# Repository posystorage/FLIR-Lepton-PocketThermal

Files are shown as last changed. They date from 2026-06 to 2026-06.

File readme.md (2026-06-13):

# FLIR LWIR Firmware README

<p align="center">
  <a href="#中文">中文</a> · <a href="#english">English</a>
</p>

## 中文

> 中文为原文，英文为机器翻译，仅供海外读者快速了解。  
> 硬件开源说明见：[`hardware/hw.md`](hardware/hw.md)。相关硬件讨论也可参考https://oshwhub.com/posy/project_xbiozslm。
> 电路板文件以本仓库hw内的AD14工程为准。不要参考LCEDA!!!!!!画这个电路板的时候，LCEDA还相当不成熟呢。

### 项目简介

这是一个用于 FLIR Lepton 2.0 热成像摄像头模块的 MCU 固件项目，单片机基于 Nuvoton M484KIDIE，是一款 Cortex-M4F、192MHz 的主控。

目前功能包括：Lepton RAW14 热图采集、MCU 端图像增强（AGC、图像超分辨率）、LCD UI、HS USB 摄像头 + 读卡器、SD 卡拍照保存和电源管理。

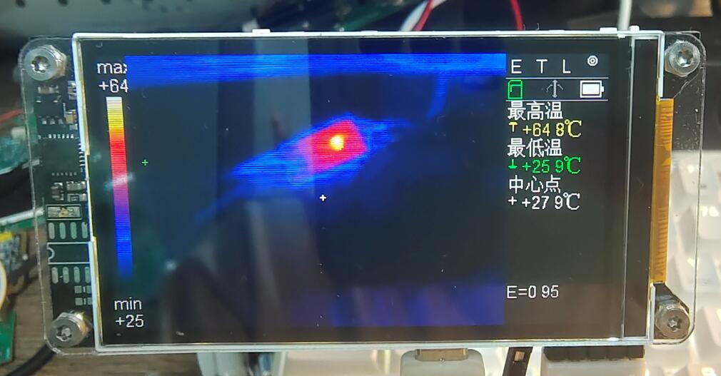
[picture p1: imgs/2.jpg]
热成像显示


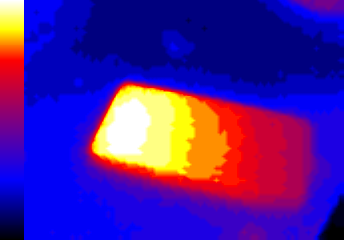
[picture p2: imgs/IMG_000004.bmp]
拍照保存 BMP 示例


Lepton 2.0 是一个 80x60 分辨率、不带测温功能的热成像摄像头模块，价格比较便宜。由于没有出厂校准的测温系数，本项目只能通过手算模型估算大致温度，可能需要二次校准才更接近真实值。建议把它作为相对温度变化的参考，而不是绝对测温仪器。

重要提醒：代码中有大量 vibe coding 内容，目前只测试了 happy path。虽然项目已经按现有文档和源码组织出完整框架，但使用、移植或复刻前必须仔细核对。

### 当前功能

- Lepton RAW14 采集，CCI 初始化和 VoSPI 帧读取。
- 512-bin Variant HEQ 风格 AGC。
- 80x60 到 320x240 的两级 2x 灰度超分。
- 支持多色卡 LUT，LCD 使用 RGB565 表，BMP 使用 RGB888 表，USB UVC 保留 YUV/灰度路径。
- RBFO 逆普朗克粗测温、发射率修正、中心/最高/最低/用户点测温。
- 432x240 手绘 UI：左侧 LUT、中间热图、右侧状态/菜单。
- MPU6050 姿态检测和 0/90/180/270 度 UI 适配。
- USB HS 复合设备：UVC 热成像摄像头 + MSC SD 读卡器。
- microSD + FatFS：保存 BMP/RAW/TXT。
- 电源管理：电池 ADC、充电状态、空闲/低电压关机、KEY1 长按关机。

### 软件架构

```text
USER/main.c
  -> SYS/       clock, tick, delay
  -> HARDWARE/  I2C, Lepton, LCD, SDH1, MPU6050, LP3921, key, UART
  -> APP/       image pipeline, UI, USB composite, UVC, storage, power manager
  -> thirdparty/fatfs/
```

主循环是裸机状态机调度，不使用 RTOS。对于一帧图像数据，当前约 8.5fps，图像处理流程约 75ms，LCD 显示约 15ms，还有约 30% 的处理器余量。HS UVC 上传仍然比较紧凑。

### 算法实现框架

图像处理分为显示链路和测温链路。AGC 只用于显示，不参与温度换算：

```text
Lepton RAW14[60][80]
  -> 显示链路: 512-bin AGC -> Gray8[60][80] -> 两级 2x 超分 -> Gray8[240][320]
  -> 测温链路: RBFO 逆普朗克 -> 发射率/校准 -> 测温点
```

超分算法位于 `firmware/APP/image_upscale.c`。它先在 80x60 灰度图上做方向感知 2x，得到 160x120；再用轻量 2x 得到 320x240；最后使用受限轻锐化。这样可以避免在伪彩色 RGB 空间插值产生色边，也能减轻普通最近邻 4x 的明显块状感。

图像流水线位于 `firmware/APP/image_proc.c`，按状态机分片推进超分，避免一次性长时间阻塞 USB、按键和 SD 服务。

### UI 框架

项目没有引入 LVGL 等通用 UI 框架，而是手绘 UI：

- `ui.c`：UI 状态机、按键分发、脏区调度。
- `ui_draw.c`：矩形、线、点阵图标、文字、LUT、RGB565 热图写屏。
- `ui_menu.c`：发射率、LUT、测温点菜单。
- `mcu_font.c` / `flir_font_16.c`：中英混合点阵字体。

UI 基础布局为 432x240：左侧 24px LUT 色条，中间 320x240 热图，右侧 88px 状态/菜单区。方向变化由 MPU6050 驱动触发，UI 在 0/90/180/270 度下重新计算 LUT 和状态栏位置。

### USB 和 SD 卡调度

USB 侧由 `usb_composite.c` 和 `usb_uvc.c` 实现：

- UVC：320x240 YUY2，图像源来自超分后的 Gray8。发送时即时生成 `Y0,128,Y1,128`，不申请整帧 YUY2 缓冲。
- MSC：把 SD 卡暴露为 USB Mass Storage。MSC 占用 SD 时，FatFS 会被释放，板端拍照保存被禁止。

SD 侧由 `sdcard.c` 提供插拔检测、挂载、异步块传输和 FatFS 接入。USB MSC 与 FatFS 通过 `SDCard_AcquireForMSC()` / `SDCard_ReleaseFromMSC()` 互斥，避免电脑和板端同时写同一张卡。

拍照保存由 `storage.c` 分片执行。保存 BMP 时每次写 4 行，并在保存期间暂停新热图处理，以保护 `g_sr_out` 和 RAW14 快照。

### 硬件注意

硬件设计时间是 2019 年，有大量今天不易采购的过时器件，更多仅供参考，不建议直接复刻。板上预留的 24C02、W25Q32、RX8010、SHT30、ESP-01 WiFi 模块均未焊接，也没有软件驱动，可以不焊接。后续若继续改板或继续改软件，可以考虑在 W25Q32 位置改接 PSRAM，以缓解当前内存紧张问题。

屏幕主控为 S6D0170，现在已经很难买到。如果要更换，建议换成 ST7789 主控的屏幕。

更完整的硬件说明见 [`hardware/hw.md`](hardware/hw.md)。

### 构建说明

项目使用 Keil MDK V6 编译器。

本 README 不代表已经在所有硬件条件下完成验证。若复刻，请先完整核对硬件、Keil 工程文件、启动文件、链接脚本和所有新增源码是否已经加入工程。

## English

> The Chinese section is the original text. This English section is machine translated and is provided only as a quick reference for non-Chinese readers.  
> Hardware documentation: [`hardware/hw.md`](hardware/hw.md). The hardware and software documents are intended for different publishing platforms; after publication, replace these relative links with the public URLs.

### Overview

This is an MCU firmware project for the FLIR Lepton 2.0 thermal camera module. The MCU is based on the Nuvoton M484KIDIE, a Cortex-M4F controller running at 192MHz.

The current firmware covers Lepton RAW14 thermal image acquisition, MCU-side image enhancement (AGC and image super-resolution), LCD UI, HS USB camera + card-reader mode, SD-card photo capture, and power management.

Thermal image display

Saved BMP example

Lepton 2.0 is an inexpensive 80x60 thermal camera module without radiometric temperature measurement. Because it does not provide factory-calibrated temperature coefficients, this project can only estimate approximate temperatures through a hand-built model. Secondary calibration may be required for better accuracy. Treat it as a reference for relative temperature changes rather than an absolute thermometer.

Important warning: there is a lot of vibe coding in this codebase, and only the happy path has been tested so far. Although the project now has a complete framework based on the current documents and source code, everything must be carefully reviewed before use, porting, or reproduction.

### Features

- Lepton RAW14 acquisition, CCI initialization, and VoSPI frame reading.
- 512-bin Variant-HEQ-style AGC.
- Two-stage 2x grayscale super-resolution from 80x60 to 320x240.
- Multiple LUT palettes. LCD uses RGB565 tables, BMP uses RGB888 tables, and USB UVC keeps a YUV/grayscale path.
- RBFO inverse-Planck rough temperature estimation, emissivity correction, and center/max/min/user temperature points.
- Hand-drawn 432x240 UI: LUT on the left, thermal image in the center, status/menu panel on the right.
- MPU6050 orientation detection and 0/90/180/270 degree UI adaptation.
- USB HS composite device: UVC thermal camera + MSC SD-card reader.
- microSD + FatFS storage for BMP/RAW/TXT files.
- Power management: battery ADC, charge status, idle/low-voltage shutdown, and KEY1 long-press shutdown.

### Software Architecture

```text
USER/main.c
  -> SYS/       clock, tick, delay
  -> HARDWARE/  I2C, Lepton, LCD, SDH1, MPU6050, LP3921, key, UART
  -> APP/       image pipeline, UI, USB composite, UVC, storage, power manager
  -> thirdparty/fatfs/
```

The main loop is a bare-metal state-machine scheduler and does not use an RTOS. For each frame, the current effective rate is about 8.5fps. Image processing takes about 75ms, LCD output takes about 15ms, and roughly 30% CPU headroom remains. HS UVC transmission is still quite tight.

### Algorithm Framework

The image pipeline is split into a display path and a temperature path. AGC is used only for display and does not participate in temperature conversion:

```text
Lepton RAW14[60][80]
  -> display path: 512-bin AGC -> Gray8[60][80] -> two-stage 2x super-resolution -> Gray8[240][320]
  -> temperature path: RBFO inverse Planck -> emissivity/calibration -> temperature points
```

The super-resolution implementation is in `firmware/APP/image_upscale.c`. It first performs direction-aware 2x interpolation on the 80x60 grayscale image to generate 160x120, then uses a lighter 2x pass to produce 320x240, followed by limited light sharpening. This avoids color fringing from interpolation in pseudo-color RGB space and reduces the blocky look of ordinary nearest-neighbor 4x scaling.

The image pipeline is implemented in `firmware/APP/image_proc.c`. It advances super-resolution in slices through a state machine, avoiding long blocking periods that would otherwise affect USB, buttons, and SD-card service.

### UI Framework

The project does not use LVGL or another general-purpose UI framework. The UI is hand drawn:

- `ui.c`: UI state machine, key dispatch, dirty-region scheduling.
- `ui_draw.c`: rectangles, lines, bitmap icons, text, LUT, and RGB565 thermal-frame output.
- `ui_menu.c`: emissivity, LUT, and temperature-point menus.
- `mcu_font.c` / `flir_font_16.c`: mixed Chinese/English bitmap fonts.

The base UI layout is 432x240: a 24px LUT strip on the left, a 320x240 thermal image in the center, and an 88px status/menu panel on the right. Orientation changes are triggered by the MPU6050 driver, and the UI recalculates LUT and status-panel positions for 0/90/180/270 degree orientations.

### USB and SD Scheduling

USB is implemented by `usb_composite.c` and `usb_uvc.c`:

- UVC: 320x240 YUY2. The image source is the super-resolved Gray8 frame. The firmware generates `Y0,128,Y1,128` on the fly and does not allocate a full-frame YUY2 buffer.
- MSC: exposes the SD card as USB Mass Storage. When MSC owns the SD card, FatFS is released and local photo capture on the device is disabled.

The SD-card layer in `sdcard.c` handles card detection, mounting, asynchronous block transfers, and FatFS integration. USB MSC and FatFS are mutually exclusive through `SDCard_AcquireForMSC()` and `SDCard_ReleaseFromMSC()`, preventing the host PC and the device from writing to the same card at the same time.

Photo capture is implemented as a sliced state machine in `storage.c`. BMP saving writes four rows at a time, and new thermal-frame processing is paused during saving to protect `g_sr_out` and the RAW14 snapshot.

### Hardware Notes

The hardware was designed in 2019 and uses many components that are now outdated or hard to source. It is mainly provided as a reference and is not recommended for direct reproduction. The reserved 24C02, W25Q32, RX8010, SHT30, and ESP-01 WiFi module footprints are not populated and have no software drivers, so they can be left unmounted. If the board or software is developed further, the W25Q32 position could potentially be adapted for PSRAM to relieve the current memory pressure.

The LCD controller is S6D0170, which is now difficult to buy. If the display is replaced, an ST7789-based screen is recommended.

For more complete hardware notes, see [`hardware/hw.md`](hardware/hw.md).

### Build Notes

The project uses the Keil MDK V6 compiler.

This README does not mean that all functions have been fully verified under all hardware conditions. If you reproduce the project, first check the hardware, Keil project files, startup files, linker script, and whether all newly added source files have been included in the project.

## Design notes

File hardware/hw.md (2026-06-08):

# FLIR LWIR 手持热成像仪硬件开源说明

<p align="center">
  <a href="#中文">中文</a> · <a href="#english">English</a>
</p>

## 中文

> 这是一份偏硬件与产品展示的开源说明。软件/固件说明请见：[`../readme.md`](../readme.md)。  
> 两份文档计划发布在不同平台，开源软件参考https://github.com/posystorage/FLIR-Lepton-PocketThermal。

### 项目简介

一个基于FLIR lepton 2.0热成像摄像头模块 和 Nuvoton M484KIDIE单片机 的手持式长波红外热成像仪硬件项目。硬件设计时间为 2019 年，挖坑后由于搞不定有效的可以跑在单片机上的图像超分辨率算法而弃坑，最近借着vibe coding热潮，可以向ai许愿了遂填坑。

目前实现了热图显示、拍照保存、USB 摄像头、SD 卡读写、姿态旋转 UI、电池和电源管理等功能。

请注意：这个硬件更多是一个历史设计，不建议直接复刻。板上使用了不少今天已经不容易采购、甚至偏过时的器件（比如屏幕直接买不到了，单片机和电源管理芯片不知道当时脑子发什么疯选的这玩意儿）；作者也不计划再做第二版。如果考虑复刻，应把它作为参考设计，而不是直接照抄 Gerber/BOM。

### 功能展示

#### 热成像显示

设备使用 FLIR Lepton 长波红外模组采集 80x60 RAW14 热图，MCU 端完成 AGC、灰度超分、伪彩色 LUT 和测温点叠加后，显示到 240x432 RGB LCD 上。

热成像显示

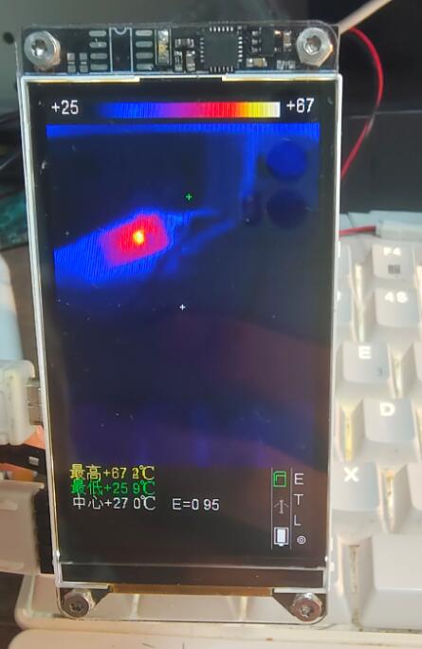
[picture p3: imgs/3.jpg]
竖屏显示


#### 拍照模式

主界面按下快门键后，固件会在 SD 卡的 `FLIR` 目录中保存三类文件：

- `IMG_xxxxxx.bmp`：344x240 BMP，包含左侧 LUT 色条和 320x240 热图，不包含右侧状态 UI。
- `RAW_xxxxxx.bin`：当前 80x60 RAW14 原始热数据。
- `DAT_xxxxxx.txt`：当前 LUT、发射率、帧号和测温点等元数据。

保存时会冻结当前帧，避免 BMP/RAW 写入过程中图像缓存被下一帧覆盖。

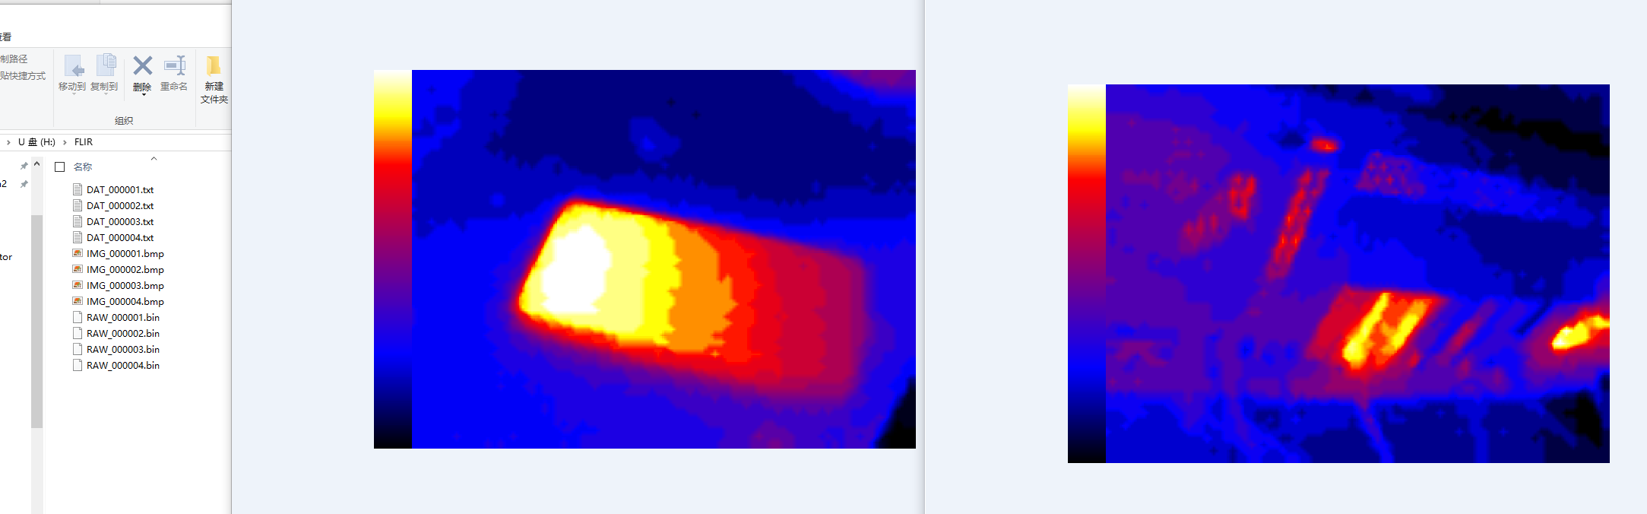
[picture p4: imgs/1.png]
拍照模式文件展示


拍照保存 BMP 示例

#### USB 摄像头模式

通过高速 USB 连接电脑后，设备会枚举为 USB 复合设备：

- UVC 摄像头：320x240 YUY2 热成像视频流。
- MSC 读卡器：电脑可访问 SD 卡内容。

画面优先保证板端 LCD 刷新流畅，因此 UVC 是 best-effort 发送。如果 USB 发送来不及完成，固件可能丢弃当前 USB 帧，以便继续处理和显示下一帧热图。

注意，不要让主机把设备降级到全速 USB，否则可能一张图像都发不出去。即使在高速 USB 下也已经很紧张：因为内存空间紧张，没有做完整双缓存，现处理出来的内容只能当场喂给 USB，图像处理本身也需要时间。

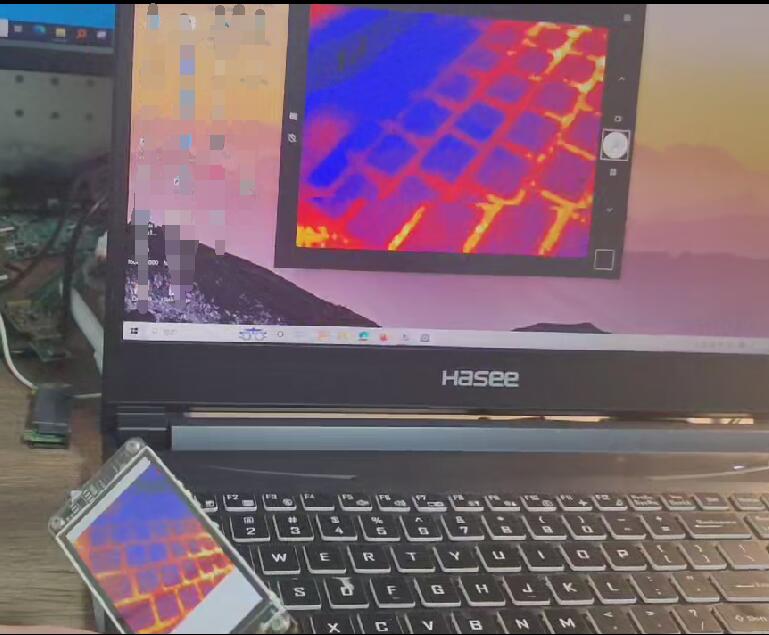
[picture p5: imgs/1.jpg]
USB UVC 摄像头模式


#### 不同 LUT 色卡效果

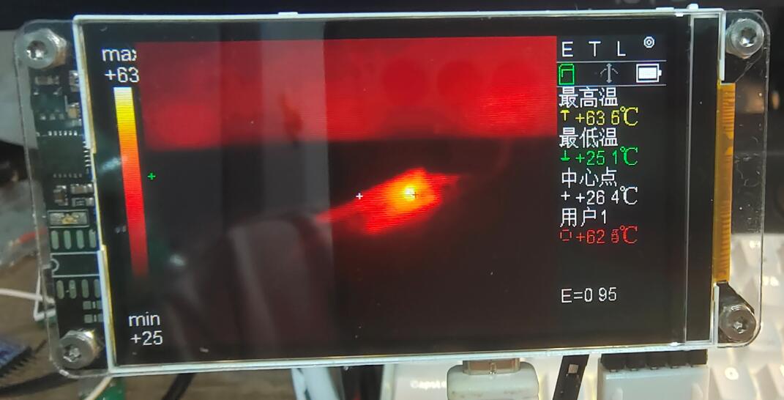
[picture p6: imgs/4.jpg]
LUT 色卡效果 1


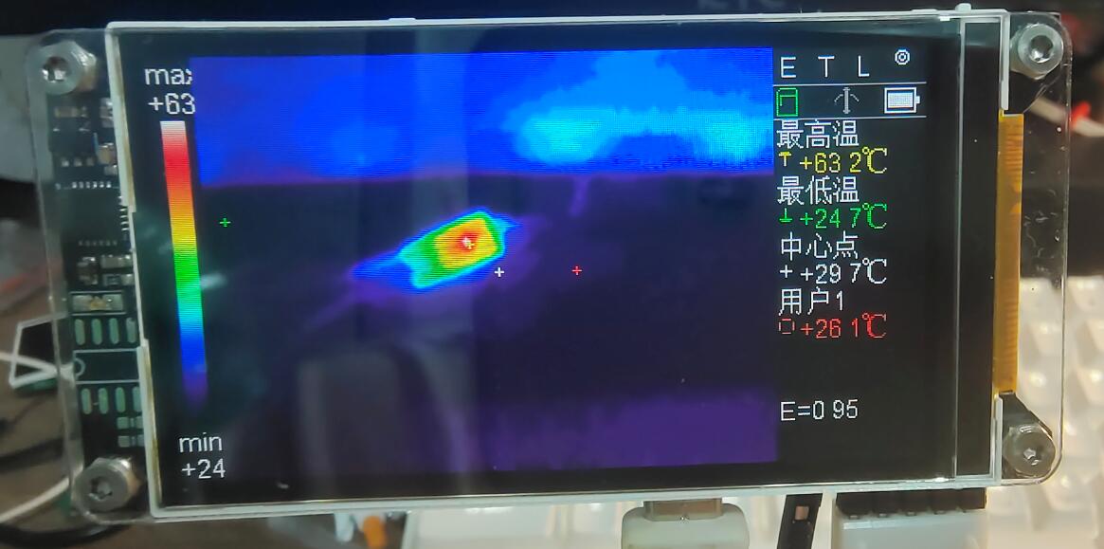
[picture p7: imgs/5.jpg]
LUT 色卡效果 2


#### 硬件焊接展示

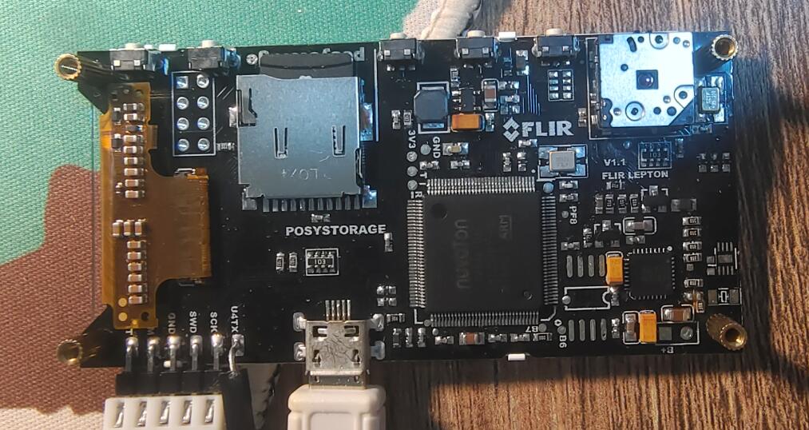
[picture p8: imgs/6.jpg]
硬件焊接展示


#### 图像超分辨率

80x60 的显示分辨率实在是没眼看，所以项目里跑了一个简易的图像超分辨率算法。

Lepton 模块支持输出彩图，也支持输出 RAW14 原始数据。如果直接对彩图做超分辨率，单片机冒烟都算不出来。所以当前方案先读取 RAW14，把原始数据 AGC 到 8-bit，然后在灰度热图上做超分辨率，最后再上色。

实现路径：

```text
80x60 RAW14
  -> 512-bin AGC 得到 80x60 Gray8
  -> 两级 2x 灰度超分得到 320x240 Gray8
  -> 查 LUT 输出 RGB565 到 LCD / 生成 BMP
```

第一级 2x 使用方向感知、受限 Catmull-Rom 中点插值，第二级使用双线性/平均，最后做轻量的受限锐化。经过测试，如果使用面向彩色图像的那种锐化，锐化会太严重，画面显得很假。

曾经尝试过在单片机上跑一个超小型神经网络算法，还专门收集了热成像训练图，PC 端也简单训练试了试；后面发现 SRAM 消耗太多，算力也跟不上，这个坑后续有机会再填吧。

传统算法在 Cortex-M4 上比较节省资源，整个图像扩展流程大概 75ms 算完，也比较适合热扩散图像的观感。

<!-- 功能展示图：最近邻 4x 与两级 2x 超分效果对比 -->

### 关键硬件

| 模块 | 关键器件/接口 | 说明 |
|---|---|---|
| 主控 | Nuvoton M484KIDIE | Cortex-M4F，系统时钟 192MHz。 |
| 红外模组 | FLIR Lepton 系列 | 当前固件按 Lepton 2.0 RAW14/VoSPI/CCI 80x60 路径整理；更换型号需核对 CCI 命令和输出格式。 |
| 显示 | 240x432 RGB LCD | 主控 S6D0170，EBI 并行接口，RGB565。 |
| 电源管理 | LP3921 PMIC + 1.2V DCDC | 为 MCU、LCD/SD、Lepton 模拟/IO/数字核心供电，并负责充电/电源保持。 |
| 姿态 | MPU6050 | 用于 0/90/180/270 度方向判定和 UI 旋转。 |
| 存储 | microSD + SDH1 | 4-bit SD 总线，FatFS 文件系统。 |
| USB | M484 HS USB | 固件实现 UVC 摄像头和 MSC 读卡器复合设备。 |
| 人机交互 | 5 个顶部按键 | 开关机、发射率选择、测温点、LUT 切换、确认/快门。 |
| 调试 | UART4 | 921600bps 调试输出。 |

### 未焊接/未实现的预留器件

电路板上预留了若干器件位，但当前样机没有焊接，也没有配套软件驱动，可以不焊：

- `24C02` EEPROM：未焊接，设置存储功能暂未实现。
- `W25Q32` SPI Flash：未焊接，当前固件暂时用不到外部 Flash；倒是可以考虑接一个 PSRAM，跑一点更炫酷的图像算法。
- `RX8010` RTC：未焊接，当前文件命名使用递增序号，实时时钟功能已搁置。
- `SHT30` 温湿度传感器：未焊接，这个位置离电源管理芯片太近，而电源管理芯片又很烫，测出来的环境温度不准，越测越假。
- `ESP-01 WiFi` 模块：未焊接，WiFi 功能已搁置。

### 已知硬件问题

调试期间发现了几个比较实际的问题：

- 摄像头位置太靠近板边。手持或调试时手容易碰到 Lepton 模组，导致模组与座子接触不良。
- 主控芯片和电源管理芯片发热较明显，而且非常靠近板载温度计预留位。
- 发热器件也离摄像头比较近，会影响红外测温精度和稳定性。
- 因为热干扰比较明显，最终没有安装板载温度计。

如果要复刻，屏幕肯定要换掉；主控建议换成带 HS USB、主频和 SRAM 都更充裕的型号，以缓解当前超分输出、中间缓存和 USB/SD 双缓冲带来的内存紧张问题。这里推荐直接考虑 GD32H757。至少也应修改摄像头位置、热源器件布局、温度传感器位置和热隔离结构。不要直接复刻当前布局。

### 软件与验证状态

固件已经实现了主循环调度、图像处理、UI、存储、USB 复合设备等大量功能，但仍有不少内容需要仔细复核。项目中有大量 vibe coding 内容，目前只测试了 happy path，代码使用前最好逐项核对。

### 复刻建议

这个硬件设计不是推荐量产方案。若只是学习，可以参考电源、Lepton、LCD、SD、USB 等模块的组织方式；若要做新板，建议重新选型并重新布局。

作者目前不打算推出第二版硬件。

## English

> This document focuses on hardware and product-level presentation. For the software/firmware notes, see [`../readme.md`](../readme.md).  
> The hardware and software documents are intended for different publishing platforms; after publication, replace these relative links with the public URLs.

### Overview

This is a handheld long-wave infrared thermal imager hardware project based on the FLIR Lepton 2.0 thermal camera module and the Nuvoton M484KIDIE MCU. The hardware was designed in 2019. I dug this hole and then abandoned it because I could not make an effective image super-resolution algorithm run on a microcontroller. Recently, with the vibe-coding wave, I can finally make wishes to AI, so I came back to fill the hole.

The current system implements thermal image display, photo capture, USB camera mode, SD-card access, orientation-aware UI rotation, battery management, and power management.

Please note that this hardware is more of a historical design and is not recommended for direct reproduction. Many components on the board are now hard to source or outdated. For example, the screen basically cannot be bought directly anymore, and I have no idea what was going through my head when I chose this MCU and PMIC. The author does not plan to make a second hardware revision. If you are considering reproducing it, treat it as a reference design rather than directly copying the Gerber files or BOM.

### Feature Demo

#### Thermal Image Display

The device uses a FLIR Lepton long-wave infrared module to capture 80x60 RAW14 thermal frames. The MCU performs AGC, grayscale super-resolution, pseudo-color LUT mapping, and temperature-point overlay, then displays the result on a 240x432 RGB LCD.

Thermal image display

Portrait display

#### Photo Mode

After pressing the shutter key on the main screen, the firmware saves three types of files into the `FLIR` directory on the SD card:

- `IMG_xxxxxx.bmp`: a 344x240 BMP containing the left LUT strip and the 320x240 thermal image, without the right-side status UI.
- `RAW_xxxxxx.bin`: the current 80x60 RAW14 thermal data.
- `DAT_xxxxxx.txt`: metadata such as current LUT, emissivity, frame number, and temperature points.

The current frame is frozen during saving, so the BMP/RAW write process will not be corrupted by the next frame overwriting the image buffer.

Photo mode file list

Saved BMP example

#### USB Camera Mode

When connected to a PC through high-speed USB, the device enumerates as a USB composite device:

- UVC camera: 320x240 YUY2 thermal video stream.
- MSC card reader: the PC can access the SD card.

The firmware prioritizes smooth LCD refresh on the device, so UVC streaming is best-effort. If USB transmission cannot finish in time, the firmware may drop the current USB frame so it can continue processing and displaying the next thermal frame.

Do not let the host downgrade the device to full-speed USB, or it may fail to transmit even one full image. Even under high-speed USB, the timing is already tight: because RAM is limited, there is no full double buffering, so newly processed image data must be fed to USB immediately while image processing itself also consumes time.

USB UVC camera mode

#### Different LUT Palette Effects

LUT palette effect 1

LUT palette effect 2

#### Hardware Soldering Showcase

Hardware soldering showcase

#### Image Super-Resolution

The native 80x60 display resolution is painfully low, so this project runs a simple image super-resolution algorithm.

The Lepton module can output both pseudo-color images and RAW14 data. If super-resolution is applied directly to the color image, the MCU would never keep up. The current approach reads RAW14 first, maps it to 8-bit grayscale through AGC, performs super-resolution on the grayscale thermal image, and applies color afterward.

Pipeline:

```text
80x60 RAW14
  -> 512-bin AGC to 80x60 Gray8
  -> two-stage 2x grayscale super-resolution to 320x240 Gray8
  -> LUT lookup to RGB565 for LCD / BMP generation
```

The first 2x stage uses direction-aware, limited Catmull-Rom midpoint interpolation. The second stage uses bilinear/average interpolation, followed by light limited sharpening. Tests showed that sharpening methods intended for color images look too harsh and fake on thermal images.

There was also an attempt to run a tiny neural-network algorithm on the MCU. Thermal training images were collected, and a simple PC-side training experiment was done. In the end, SRAM usage and compute cost were too high, so that idea is left for the future.

The traditional algorithm is much more resource-friendly on Cortex-M4. The whole image expansion process takes about 75ms and also looks more natural for heat-diffusion imagery.

<!-- Demo image: nearest-neighbor 4x vs two-stage 2x super-resolution comparison -->

### Key Hardware

| Module | Key component/interface | Notes |
|---|---|---|
| MCU | Nuvoton M484KIDIE | Cortex-M4F, 192MHz system clock. |
| Infrared module | FLIR Lepton series | Current firmware is organized around the Lepton 2.0 RAW14/VoSPI/CCI 80x60 path. Other models require checking CCI commands and output formats. |
| Display | 240x432 RGB LCD | S6D0170 controller, EBI parallel interface, RGB565. |
| Power management | LP3921 PMIC + 1.2V DCDC | Powers MCU, LCD/SD, Lepton analog/IO/digital core, and handles charging and power hold. |
| Orientation | MPU6050 | Used for 0/90/180/270 degree orientation detection and UI rotation. |
| Storage | microSD + SDH1 | 4-bit SD bus with FatFS. |
| USB | M484 HS USB | Firmware implements a composite UVC camera and MSC card reader. |
| Interaction | 5 top buttons | Power, emissivity selection, temperature points, LUT switching, confirm/shutter. |
| Debug | UART4 | 921600bps debug output. |

### Unpopulated / Unimplemented Reserved Parts

Several footprints are reserved on the PCB, but they are not populated on the current prototype and have no software drivers. They can be left unmounted:

- `24C02` EEPROM: not populated; settings storage is not implemented.
- `W25Q32` SPI Flash: not populated; the current firmware does not need external Flash. This position could potentially be adapted for PSRAM to run more ambitious image algorithms.
- `RX8010` RTC: not populated; current file naming uses an incrementing sequence number, and real-time clock support is postponed.
- `SHT30` temperature/humidity sensor: not populated. Its position is too close to the PMIC, and the PMIC runs hot, so the measured ambient temperature would be inaccurate.
- `ESP-01 WiFi` module: not populated; WiFi support is postponed.

### Known Hardware Issues

Several practical issues were found during debugging:

- The camera is too close to the board edge. During handheld use or debugging, it is easy to touch the Lepton module, causing poor contact between the module and its socket.
- The MCU and PMIC produce noticeable heat and are very close to the reserved onboard thermometer position.
- These heat sources are also close to the camera and can affect infrared temperature accuracy and stability.
- Because the thermal interference was obvious, the onboard thermometer was ultimately not installed.

If you reproduce the design, the display should definitely be replaced. The MCU should preferably be replaced with a part that has HS USB and more CPU frequency and SRAM, to relieve the current memory pressure from super-resolution buffers and USB/SD buffering. GD32H757 is a direct candidate to consider. At minimum, change the camera position, heat-source layout, temperature-sensor position, and thermal isolation. Do not directly copy the current layout.

### Software and Verification Status

The firmware already implements main-loop scheduling, image processing, UI, storage, and USB composite-device functions. However, many parts still need careful review. The project contains a lot of vibe coding, and only the happy path has been tested so far. Review the code item by item before use.

### Reproduction Advice

This hardware design is not recommended as a production-ready design. For learning, it can be used as a reference for the power, Lepton, LCD, SD, and USB module organization. For a new board, choose newer components and redo the layout.

The author currently does not plan to make a second hardware revision.

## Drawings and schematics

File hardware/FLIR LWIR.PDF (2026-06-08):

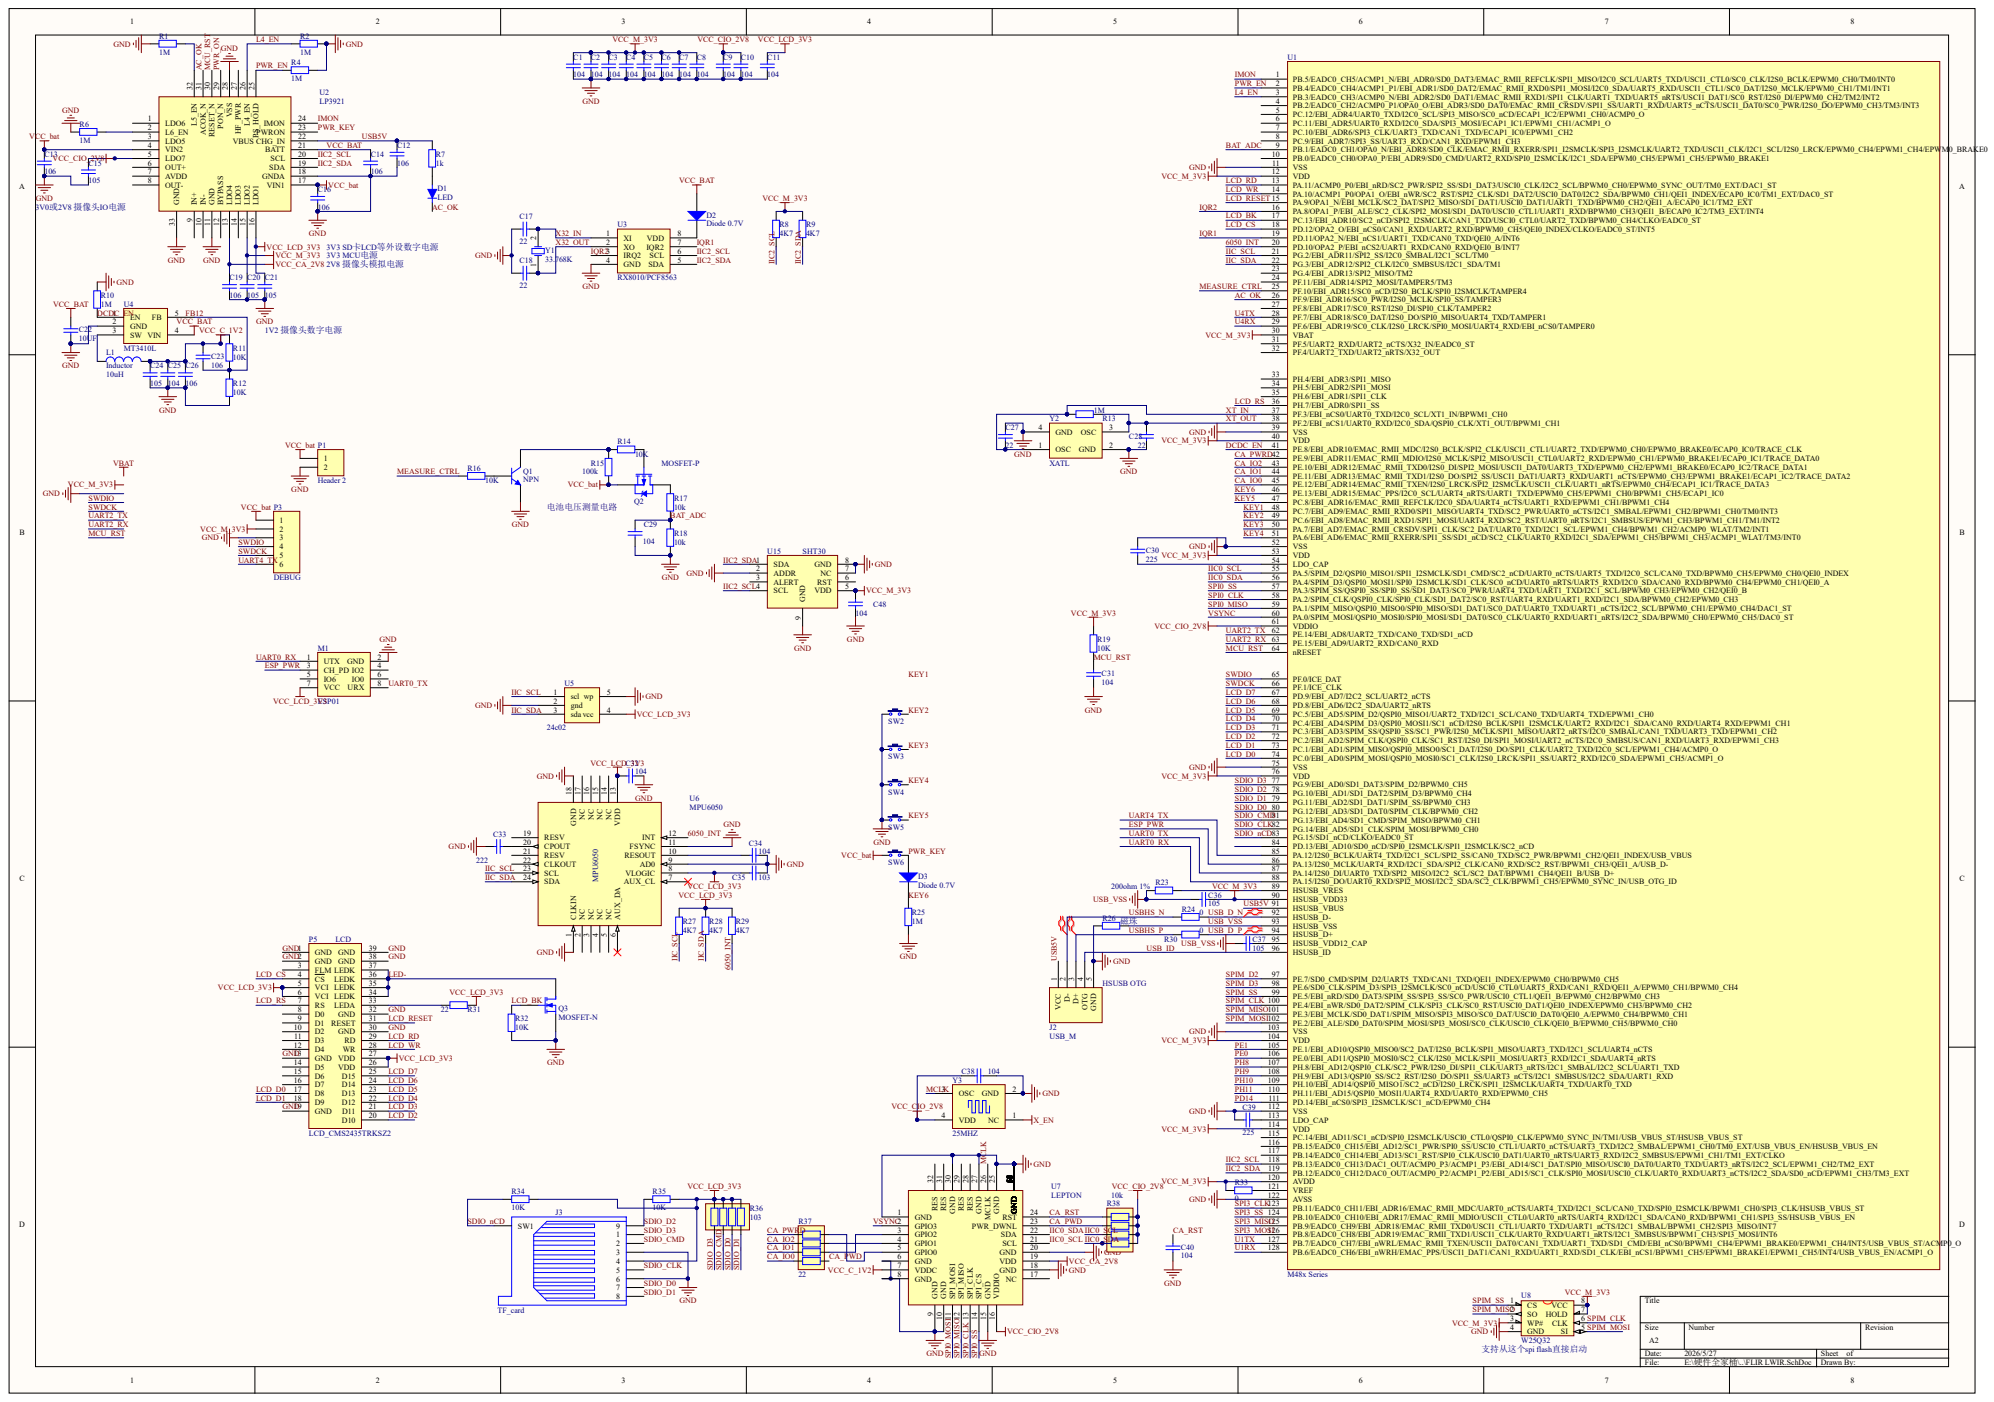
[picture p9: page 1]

22 | DCDC_EN

VDD 13 NC 14 NC 15 NC 16 NC 17 GND 18

CPOUT 20 | UART0_RX

UART0_TX SDIO_nCD

R26 磁珠 | USB_VSS

R30 USB_ID | C37 USB_VSS 105

24 ND 25 MCLK 26 GND 27 RES 28 RES 29 GND 30 RES 31 RES 32

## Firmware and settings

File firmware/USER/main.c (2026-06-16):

#include "stdio.h"
#include "M480.h"
#include "delay.h"
#include "system_init.h"
#include "sys_tick.h"
#include "lp3921.h"
#include "lcd.h"
#include "lepton.h"
#include "lepton_app.h"
#include "key.h"
#include "uart4.h"
#include "debug.h"
#include "sdcard.h"
#include "power_manager.h"
#include "mpu6050.h"
#include "usb_composite.h"
#include "storage.h"
#include "config_store.h"
#include "ui.h"
#include "ff.h"
#include "diskio.h"

#define ENABLE_FATFS_TEST  0

uint8_t test_run = 0;

#if ENABLE_FATFS_TEST
static void FATFS_Test(void)
{
    FIL fil;
    FRESULT res;
    UINT bw, br;
    char buf[64];
    DIR dir;
    FILINFO fno;

    if (test_run) return;
    test_run = 1;

    res = f_open(&fil, "0:test.txt", FA_CREATE_ALWAYS | FA_WRITE);
    if (res == FR_OK) {
        f_write(&fil, "Hello from FLIR LWIR!\r\n", 23, &bw);
        f_close(&fil);
        SD_DEBUG("write test.txt ok, bytes=%u", (unsigned int)bw);
    } else {
        SD_DEBUG("f_open write err: %d", (int)res);
    }

    res = f_open(&fil, "0:test.txt", FA_READ);
    if (res == FR_OK) {
        f_read(&fil, buf, sizeof(buf) - 1, &br);
        buf[br] = 0;
        f_close(&fil);
        SD_DEBUG("read test.txt: '%s'", buf);
    }

    res = f_opendir(&dir, "0:");
    if (res == FR_OK) {
        SD_DEBUG("root dir:");
        while (f_readdir(&dir, &fno) == FR_OK && fno.fname[0]) {
            SD_DEBUG("  %s%s  %lu", fno.fname,
                     (fno.fattrib & AM_DIR) ? "/" : "",
                     (unsigned long)fno.fsize);
        }
        f_closedir(&dir);
    }
    SD_DEBUG("FS test done");
}
#endif

void Debug_GPIO_Init(void)
{
    PA14 = 1;
    PA15 = 1;
    PA->MODE &= ~0xF0000000;
    PA->MODE |= 0x50000000;
}

int32_t main(void)
{
    delay_init();
    Timer0_Init();
    Uart4_Init();
    Power_Init();
    Key_Init();
    Debug_GPIO_Init();

    LP3921_ENABLE_PER();
    SDCard_Init();
    LCD_Init();
    MPU6050_Init();
    ConfigStore_Init();
    Lepton_HW_Prepare();
    USB_Composite_Init();
    Lepton_App_Init();
    Storage_Init();
    UI_Init();
    ConfigStore_Apply();

    HW_DEBUG("boot ok\r\n");

    while (1)
    {
        key_event_t ev;

        if (!Storage_IsBusy()) {
            Lepton_Frame_Service();
        }

        while (Key_GetEvent(&ev))
        {
            Power_OnKeyEvent(ev.key_id, ev.event);
            UI_OnKeyEvent(&ev);
        }

        Power_Service();
        SDCard_Service();
        Storage_Service();
        ConfigStore_Service();
        UI_Service();
#if ENABLE_FATFS_TEST
        FATFS_Test();
#endif
        USB_Composite_Service();
    }
}

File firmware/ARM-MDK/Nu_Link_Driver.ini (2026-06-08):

[Version]
Nu_LinkVersion=V5.2
[Process]
ProcessID=0x00002058
ProcessCreationTime_L=0xb81312ad
ProcessCreationTime_H=0x01d4b1fb
NuLinkID=0x7788b1fe
NuLinkID0=0x7788b1fe
NuLinkIDs_Count=0x00000001
[ChipSelect]
;ChipName=<NUC1xx|NUC2xx|M05x|N571|N572|Nano100|N512|Mini51|NUC505|General>
ChipName=M481
[NUC505]
Reset=Autodetect
MaxClock=1MHz
MemoryVerify=1
IOVoltage=3300
Erase=1
Program=1
Verify=1
ResetAndRun=0
EnableFlashBreakpoint=0
EnableLog=0
MemAccessWhileRun=0
RAMForAlgorithmStart=0x20000000
RAMForAlgorithmSize=0x4000
ProgramAlgorithm=NUC505_SPIFLASH.FLM
Connect=0
[NUC4xx]
Reset=Autodetect
MaxClock=1MHz
MemoryVerify=1
IOVoltage=3300
FlashSelect=APROM
Erase=1
Program=1
Verify=1
ResetAndRun=0
EnableFlashBreakpoint=1
EnableLog=0
MemAccessWhileRun=0
RAMForAlgorithmStart=0x20000000
RAMForAlgorithmSize=0x4000
ProgramAlgorithm=NUC400_AP_512.FLM
Connect=0
TraceConf0=0x00000002
TraceConf1=0x014fb180
TraceConf2=0x00000800
TraceConf3=0x00000000
TraceConf4=0x00000001
TraceConf5=0x00000000
[NUC2xx]
Reset=Autodetect
MaxClock=1MHz
MemoryVerify=1
IOVoltage=3300
FlashSelect=APROM
Erase=1
Program=1
Verify=1
ResetAndRun=0
EnableFlashBreakpoint=1
EnableLog=0
MemAccessWhileRun=0
RAMForAlgorithmStart=0x20000000
RAMForAlgorithmSize=0x1000
ProgramAlgorithm=NUC200_AP_128.FLM
Connect=0
[NUC1xx]
Reset=Autodetect
MaxClock=1MHz
MemoryVerify=1
IOVoltage=3300
FlashSelect=APROM
Erase=1
Program=1
Verify=1
ResetAndRun=0
EnableFlashBreakpoint=1
EnableLog=0
MemAccessWhileRun=0
RAMForAlgorithmStart=0x20000000
RAMForAlgorithmSize=0x1000
ProgramAlgorithm=NUC100_AP_128.FLM
Connect=0
[NUC029]
Reset=Autodetect
MaxClock=1MHz
MemoryVerify=1
IOVoltage=3300
FlashSelect=APROM
Erase=1
Program=1
Verify=1
ResetAndRun=0
EnableFlashBreakpoint=1
EnableLog=0
MemAccessWhileRun=0
RAMForAlgorithmStart=0x20000000
RAMForAlgorithmSize=0x800
ProgramAlgorithm=NUC029_AP_16.FLM
Connect=0
[NM1500]
Reset=Autodetect
MaxClock=1MHz
MemoryVerify=1
IOVoltage=3300
FlashSelect=APROM
Erase=1
Program=1
Verify=1
ResetAndRun=0
EnableFlashBreakpoint=1
EnableLog=0
MemAccessWhileRun=0
RAMForAlgorithmStart=0x20000000
RAMForAlgorithmSize=0x1000
ProgramAlgorithm=NM1500_AP_128.FLM
Connect=0
[NM1200]
Reset=Autodetect
MaxClock=1MHz
MemoryVerify=1
IOVoltage=3300
FlashSelect=APROM
Erase=1
Program=1
Verify=1
ResetAndRun=0
EnableFlashBreakpoint=1
EnableLog=0
MemAccessWhileRun=0
RAMForAlgorithmStart=0x20000000
RAMForAlgorithmSize=0x800
ProgramAlgorithm=NM1200_AP_8.FLM
Connect=0
[Nano100]
Reset=Autodetect
MaxClock=1MHz
MemoryVerify=1
IOVoltage=3300
FlashSelect=APROM
Erase=1
Program=1
Verify=1
ResetAndRun=0
EnableFlashBreakpoint=1
EnableLog=0
MemAccessWhileRun=0
RAMForAlgorithmStart=0x20000000
RAMForAlgorithmSize=0x1000
ProgramAlgorithm=Nano100_AP_64.FLM
Connect=0
[N572]
Reset=Autodetect
MaxClock=1MHz
MemoryVerify=1
IOVoltage=3300
Erase=1
Program=1
Verify=1
ResetAndRun=0
EnableFlashBreakpoint=1
EnableLog=0
MemAccessWhileRun=0
RAMForAlgorithmStart=0x20000000
RAMForAlgorithmSize=0x2000
ProgramAlgorithm=N572Fxxx.FLM
Connect=0
[N571]
Reset=Autodetect
MaxClock=1MHz
MemoryVerify=1
IOVoltage=3300
Erase=1
Program=1
Verify=1
ResetAndRun=0
EnableFlashBreakpoint=1
EnableLog=0
MemAccessWhileRun=0
RAMForAlgorithmStart=0x20000000
RAMForAlgorithmSize=0x2000
ProgramAlgorithm=N571E000.FLM
Connect=0
[N512]
Reset=Autodetect
MaxClock=1MHz
MemoryVerify=1
IOVoltage=3300
FlashSelect=APROM
Erase=1
Program=1
Verify=1
ResetAndRun=0
EnableFlashBreakpoint=1
EnableLog=0
MemAccessWhileRun=0
RAMForAlgorithmStart=0x20000000
RAMForAlgorithmSize=0x1000
ProgramAlgorithm=N512_AP_64.FLM
Connect=0
[Mini51]
Reset=Autodetect
MaxClock=1MHz
MemoryVerify=1
IOVoltage=3300
FlashSelect=APROM
Erase=1
Program=1
Verify=1
ResetAndRun=0
EnableFlashBreakpoint=1
EnableLog=0
MemAccessWhileRun=0
RAMForAlgorithmStart=0x20000000
RAMForAlgorithmSize=0x800
ProgramAlgorithm=Mini51_AP_16.FLM
Connect=0
[M451]
Reset=Autodetect
MaxClock=1MHz
MemoryVerify=0
IOVoltage=3300
FlashSelect=APROM
Erase=1
Program=1
Verify=1
ResetAndRun=0
EnableFlashBreakpoint=1
EnableLog=0
MemAccessWhileRun=0
RAMForAlgorithmStart=0x20000000
RAMForAlgorithmSize=0x4000
ProgramAlgorithm=M451_AP_256.FLM
Connect=0
[M0518]
Reset=Autodetect
MaxClock=1MHz
MemoryVerify=1
IOVoltage=3300
FlashSelect=APROM
Erase=1
Program=1
Verify=1
ResetAndRun=0
EnableFlashBreakpoint=1
EnableLog=0
MemAccessWhileRun=0
RAMForAlgorithmStart=0x20000000
RAMForAlgorithmSize=0x1000
ProgramAlgorithm=M0518_AP_64.FLM
Connect=0
[M05x]
Reset=Autodetect
MaxClock=1MHz
MemoryVerify=1
IOVoltage=3300
FlashSelect=APROM
Erase=1
Program=1
Verify=1
ResetAndRun=0
EnableFlashBreakpoint=1
EnableLog=0
MemAccessWhileRun=0
RAMForAlgorithmStart=0x20000000
RAMForAlgorithmSize=0x800
ProgramAlgorithm=M0516_AP_64.FLM
Connect=0
[ISD9300]
Reset=Autodetect
MaxClock=1MHz
MemoryVerify=1
IOVoltage=3300
FlashSelect=APROM
Erase=1
Program=1
Verify=1
ResetAndRun=0
EnableFlashBreakpoint=0
EnableLog=0
MemAccessWhileRun=0
RAMForAlgorithmStart=0x20000000
RAMForAlgorithmSize=0x1000
ProgramAlgorithm=ISD9300_AP_145.FLM
Connect=0
[ISD9xxx]
Reset=Autodetect
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

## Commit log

2026-06-08 Initial open source release
    [FLIR LWIR.PcbDoc, FLIR LWIR.SchDoc]
2026-06-08 Track references documentation
2026-06-13 Refactor UI and add manual FFC
    Refactor the UI into smaller modules, improve the visual layout, fix multiple display bugs, and add manual FFC support with status indication.
    [main.c]
2026-06-15 Improve temperature point editing
